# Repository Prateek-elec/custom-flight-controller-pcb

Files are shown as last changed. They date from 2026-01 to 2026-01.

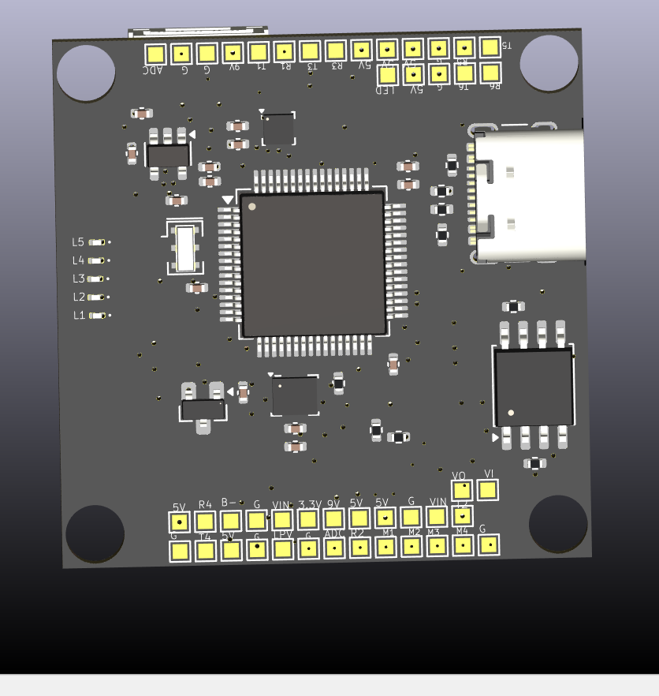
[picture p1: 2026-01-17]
docs/images/Screenshot 2026-01-17 221942.png

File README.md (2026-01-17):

# Custom Drone Flight Controller PCB (KiCad)

A custom-designed drone flight controller PCB built for UAV / robotics applications.
This repository contains schematic + PCB layout designed in **KiCad**, along with documentation and renders.

---

## 🔥 Highlights
- Custom Flight Controller PCB (compact layout)
- Designed for UAV multirotor / robotics use cases
- Includes power regulation, sensor interfaces, and IO headers
- Designed for debugging + expandability

---

## 🧩 Major Blocks (Hardware Architecture)
### ✅ MCU / Processing
- STM32-based microcontroller (flight control core)
- Clocking + reset/boot support

### ✅ Sensors
- IMU interface for attitude estimation (gyro + accel)
- Additional I2C/SPI expansion for future sensors

### ✅ Power System
- Multiple regulated rails for clean operation
- USB/VBUS support
- Protection + filtering for stable power delivery

### ✅ IO / Connectivity
- Motor/ESC outputs (PWM)
- UART ports for telemetry / GPS / RC
- I2C / SPI headers for peripherals
- Status LEDs for debugging/health indication

---

## 🖼️ PCB Preview

### 3D View
3D Render

### Schematic
Schematic

---

## 📂 Repository Structure
- `hardware/kicad/` → KiCad source project files
- `docs/images/` → PCB renders & schematic snapshots
- `fabrication/` → Gerbers, drill files, BOM, pick & place
- `firmware/` → Placeholder for future flight firmware integration

---

## 🛠️ Tools Used
- KiCad (Schematic + PCB + 3D viewer)
- Standard PCB manufacturing flow (Gerber + drill export)

---

## ✅ Project Status
- [x] Schematic completed
- [x] PCB layout completed
- [ ] Full firmware integration (planned)
- [ ] Flight testing & tuning (planned / in-progress)

---

## ⚡ Notes
This is a custom hardware project made for learning, experimentation and UAV development.
You can reuse the structure for educational purposes.

---

## 📌 Author
**Prateek Sarkar**  
UAV Systems | Embedded | PCB Design | Robotics

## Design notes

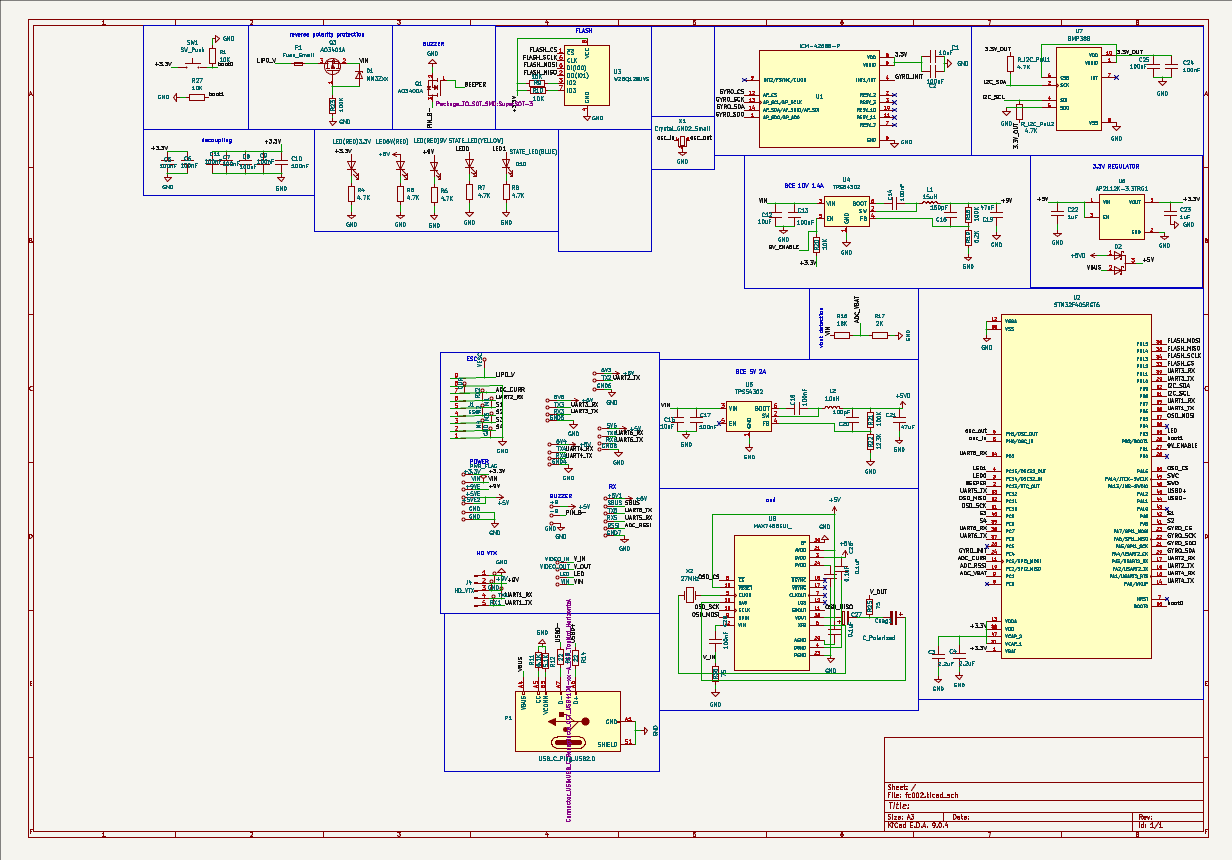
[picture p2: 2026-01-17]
docs/images/Screenshot 2026-01-17 221852.png

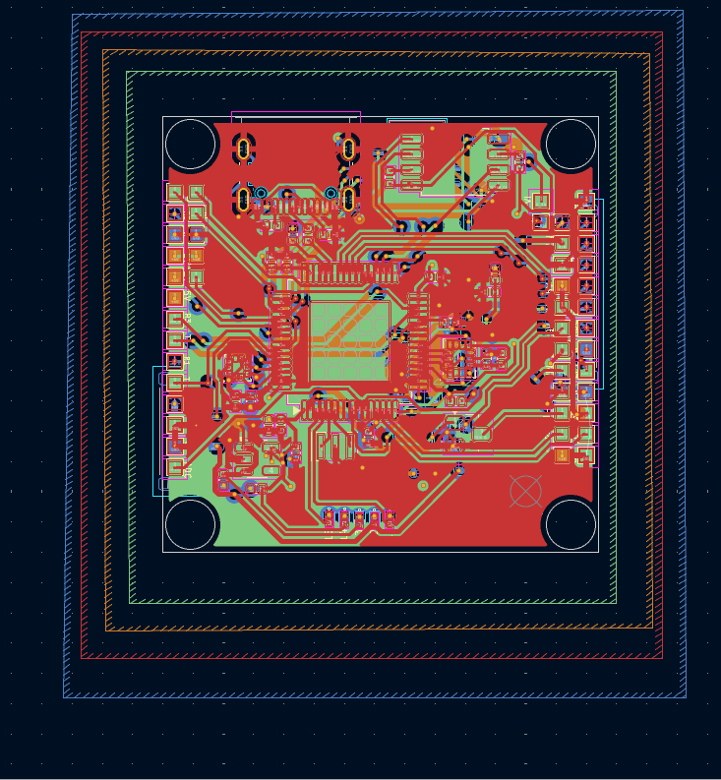
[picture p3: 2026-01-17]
docs/images/Screenshot 2026-01-17 221922.png

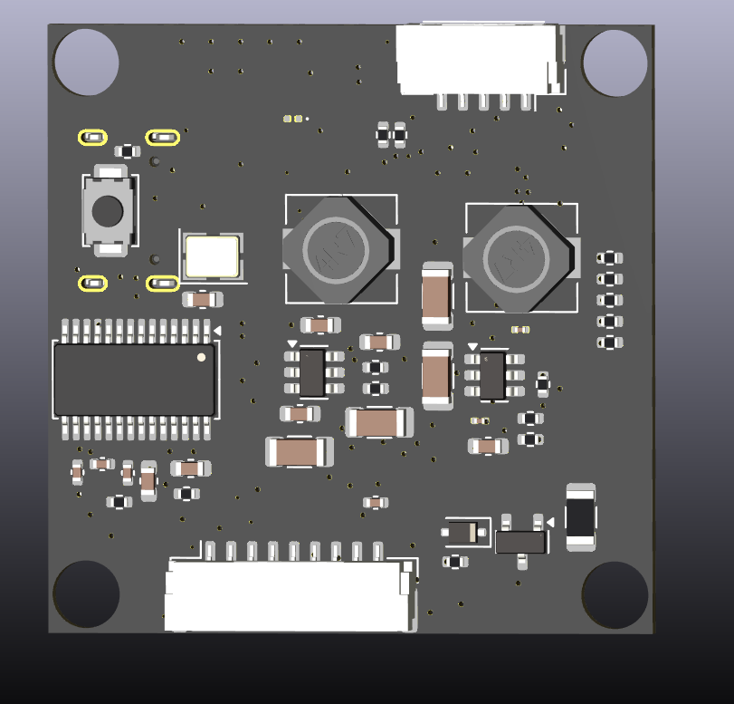
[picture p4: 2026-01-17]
docs/images/Screenshot 2026-01-17 222008.png

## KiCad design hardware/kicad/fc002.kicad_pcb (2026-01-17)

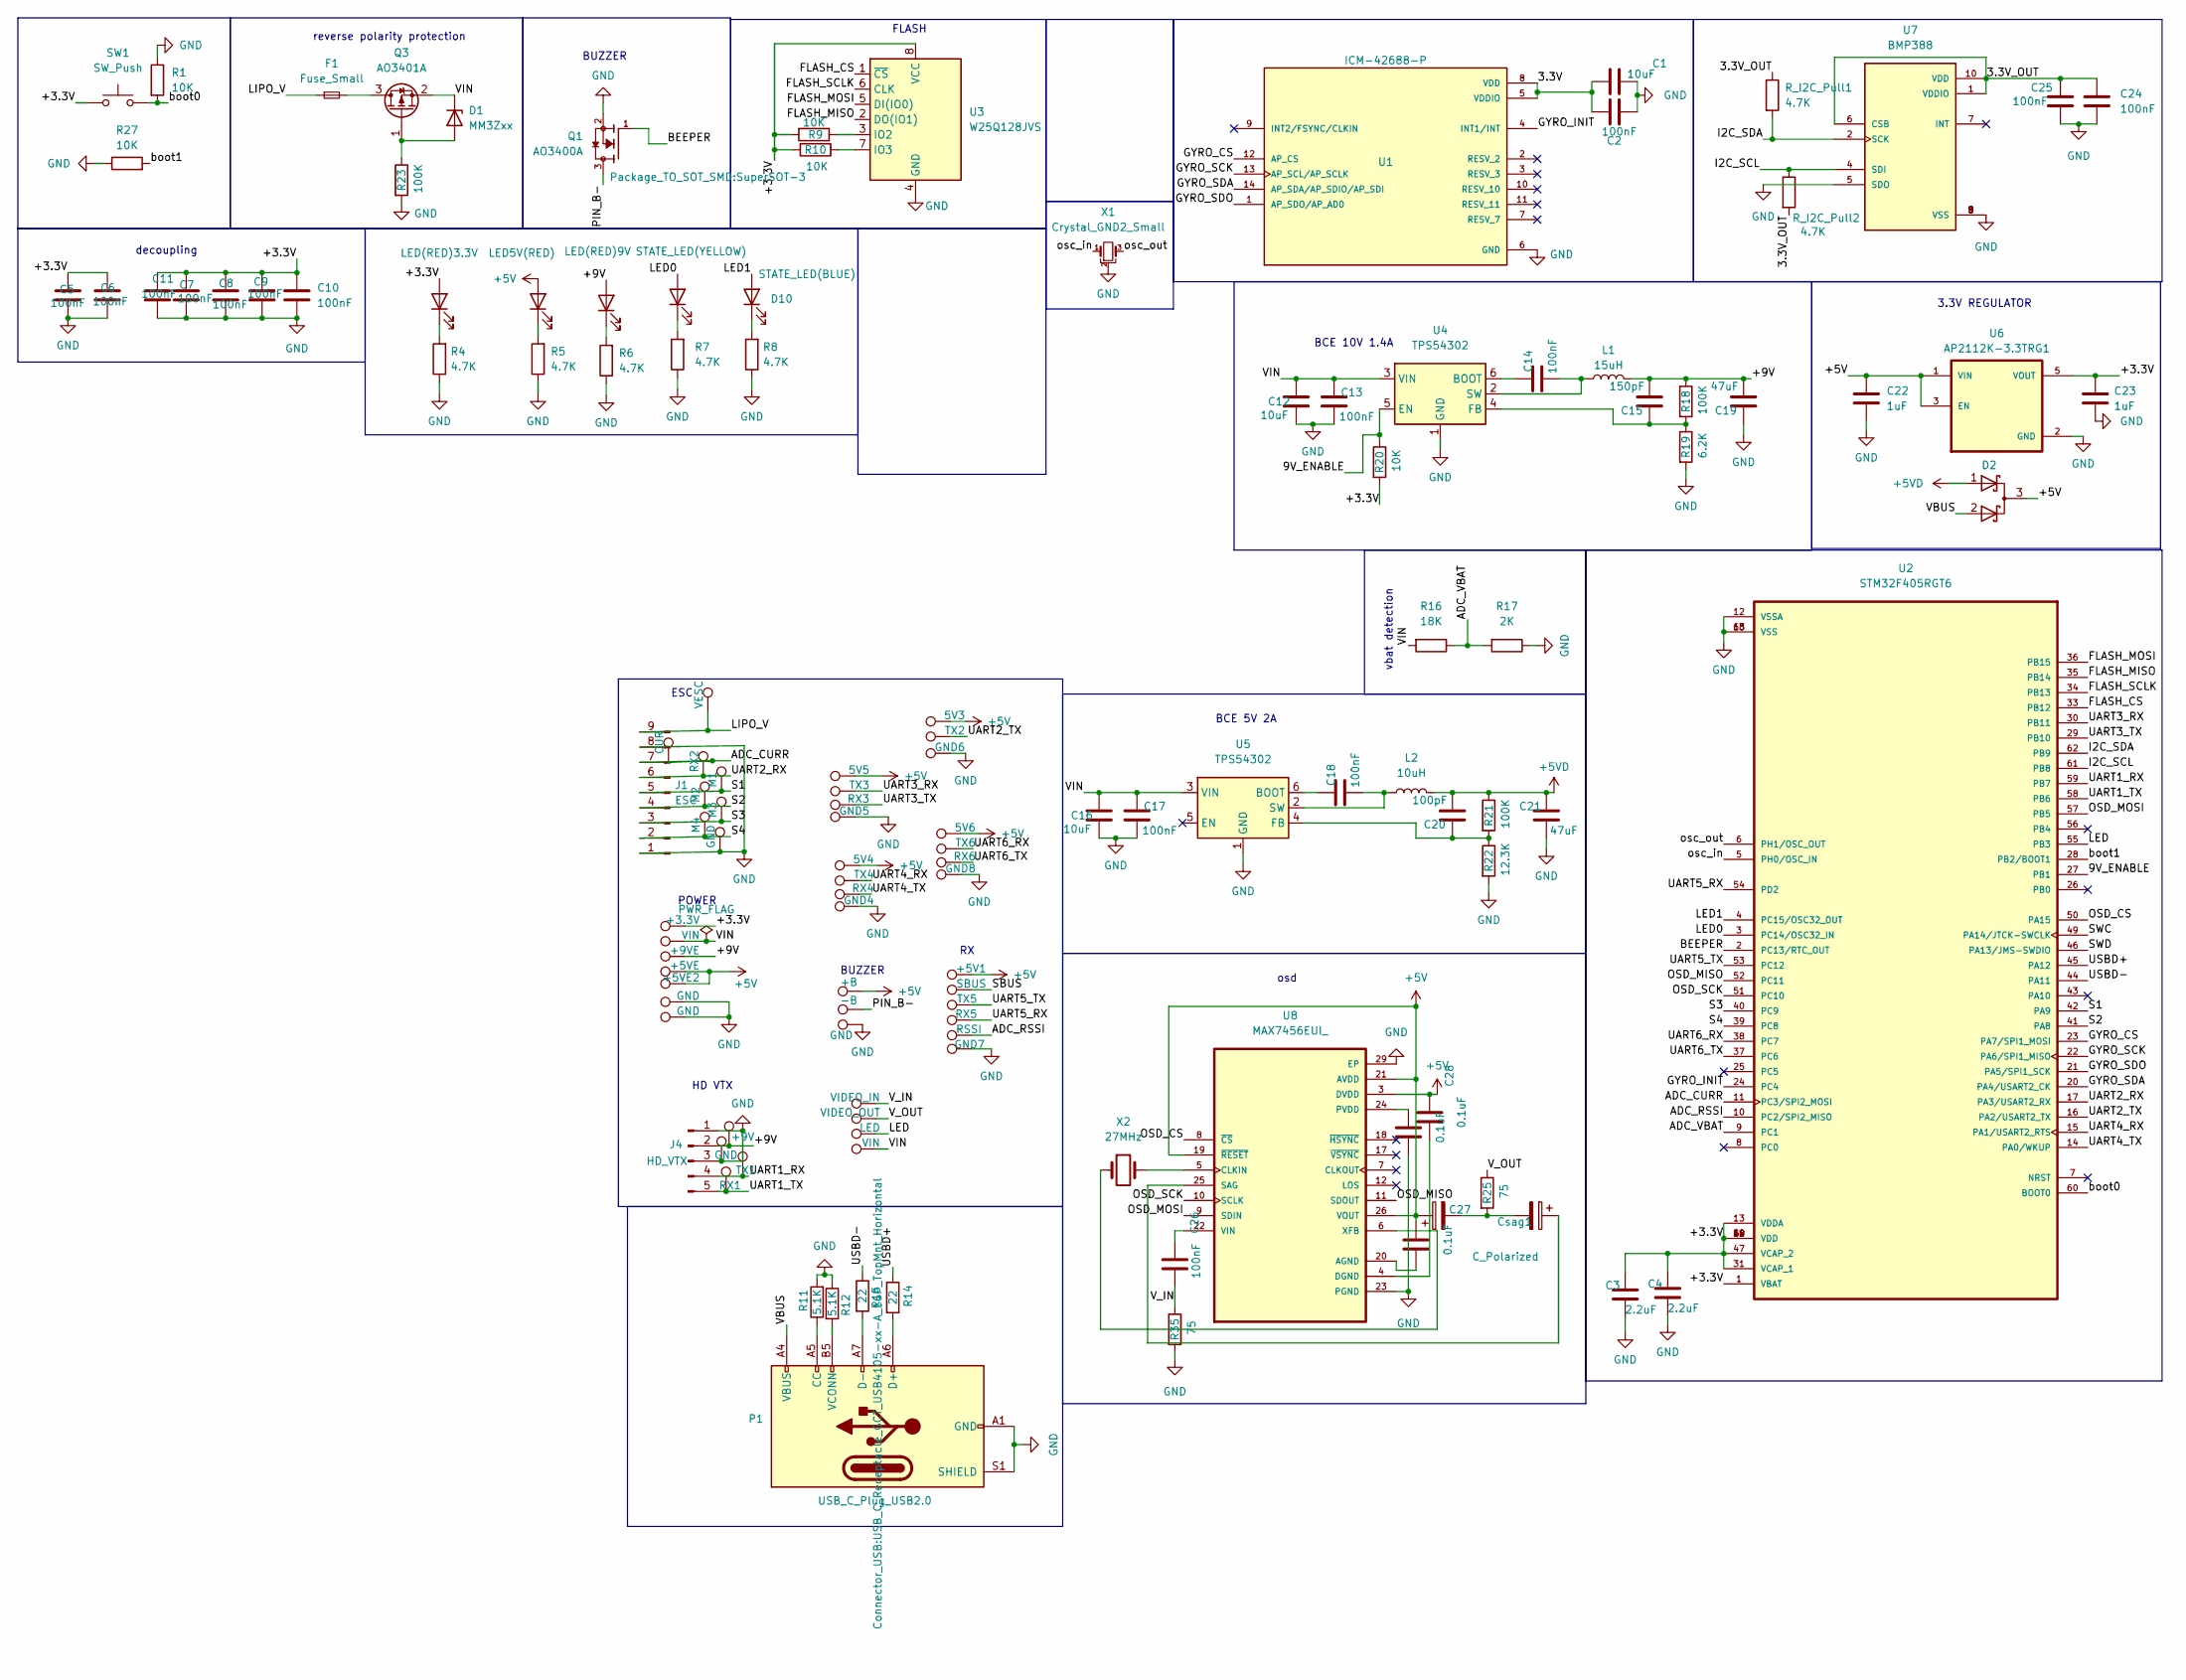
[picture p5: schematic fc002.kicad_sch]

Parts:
C1: 10uF; C_0402_1005Metric
C2, C5, C6, C7, C8, C9, C10, C11, C24, C25, C26: 100nF; C_0402_1005Metric
C3, C4: 2.2uF; C_0402_1005Metric
C12, C16: 10uF; C_1206_3216Metric
C13, C14: 100nF; C_0201_0603Metric
C15: 150pF; C_0603_1608Metric
C17, C18: 100nF; C_0603_1608Metric
C19, C21: 47uF; C_1206_3216Metric
C20: 100pF; C_0603_1608Metric
C22, C23: 1uF; C_0402_1005Metric
C27: C_Polarized; C_0603_1608Metric
C28: 0.1uF; C_0603_1608Metric
C_IMU_100n4, C_IMU_100n5: 0.1uF; C_0402_1005Metric
Csag1: C_Polarized; C_0603_1608Metric
D1: MM3Zxx; D_SOD-323F
D2: D_Schottky_Dual_CommonCathode_AAK_Parallel; D_0201_0603Metric
D10: STATE_LED(BLUE); LED_0201_0603Metric
D11: STATE_LED(YELLOW); LED_0201_0603Metric
D12: LED(RED)9V; LED_0201_0603Metric
D13: LED5V(RED); LED_0201_0603Metric
D14: LED(RED)3.3V; LED_0201_0603Metric
F1: Fuse_Small; Fuse_1206_3216Metric
J1: ESC; JST_GH_SM09B-GHS-TB_1x09-1MP_P1.25mm_Horizontal
J4: HD_VTX; JST_GH_SM05B-GHS-TB_1x05-1MP_P1.25mm_Horizontal
L1: 15uH; L_6.3x6.3_H3
L2: 10uH; L_6.3x6.3_H3
P1: USB_C_Plug_USB2.0; USB_C_Receptacle_GCT_USB4105-xx-A_16P_TopMnt_Horizontal
Q1: AO3400A; SuperSOT-3
Q3: AO3401A; SOT-23
R1, R9, R10, R20, R27: 10K; R_0402_1005Metric
R4, R5, R6, R7, R8: 4.7K; R_0402_1005Metric
R11, R12: 5.1K; R_0402_1005Metric
R14, R15: 22; R_0402_1005Metric
R16: 18K; R_0402_1005Metric
R17: 2K; R_0402_1005Metric
R18, R21, R23: 100K; R_0402_1005Metric
R19: 6.2K; R_0402_1005Metric
R22: 12.3K; R_0402_1005Metric
R25, R35: 75; R_0402_1005Metric
R_I2C_Pull1, R_I2C_Pull2: 4.7K; R_0402_1005Metric
SW1: SW_Push; SW_SPST_TS-1088-xR020
TP1: +9V; TestPoint_Pad_1.0x1.0mm
TP2: TX1; TestPoint_Pad_1.0x1.0mm
TP3: RX1; TestPoint_Pad_1.0x1.0mm
TP4, TP6, TP26, TP32, TP33: GND; TestPoint_Pad_1.0x1.0mm
TP5: -B; TestPoint_Pad_1.0x1.0mm
TP7: +5V1; TestPoint_Pad_1.0x1.0mm
TP8: SBUS; TestPoint_Pad_1.0x1.0mm
TP9: TX5; TestPoint_Pad_1.0x1.0mm
TP10: RX5; TestPoint_Pad_1.0x1.0mm
TP11: RSSI; TestPoint_Pad_1.0x1.0mm
TP12: GND7; TestPoint_Pad_1.0x1.0mm
TP15: VIDEO_IN; TestPoint_Pad_1.0x1.0mm
TP16: VIDEO_OUT; TestPoint_Pad_1.0x1.0mm
TP17: LED; TestPoint_Pad_1.0x1.0mm
TP18, TP28: VIN; TestPoint_Pad_1.0x1.0mm
TP19: VESC; TestPoint_Pad_1.0x1.0mm
TP20: CUR; TestPoint_Pad_1.0x1.0mm
TP21: RX2; TestPoint_Pad_1.0x1.0mm
TP22: M1; TestPoint_Pad_1.0x1.0mm
TP23: M2; TestPoint_Pad_1.0x1.0mm
TP24: M3; TestPoint_Pad_1.0x1.0mm
TP25: M4; TestPoint_Pad_1.0x1.0mm
TP27: +3.3V; TestPoint_Pad_1.0x1.0mm
TP29: +9VE; TestPoint_Pad_1.0x1.0mm
TP30: +5VE; TestPoint_Pad_1.0x1.0mm
TP31: +5VE2; TestPoint_Pad_1.0x1.0mm
TP34: 5V5; TestPoint_Pad_1.0x1.0mm
TP35: TX3; TestPoint_Pad_1.0x1.0mm
TP36: RX3; TestPoint_Pad_1.0x1.0mm
TP37: GND5; TestPoint_Pad_1.0x1.0mm
TP38: 5V4; TestPoint_Pad_1.0x1.0mm
TP39: TX4; TestPoint_Pad_1.0x1.0mm
TP40: RX4; TestPoint_Pad_1.0x1.0mm
TP41: GND4; TestPoint_Pad_1.0x1.0mm
TP42: 5V3; TestPoint_Pad_1.0x1.0mm
TP43: TX2; TestPoint_Pad_1.0x1.0mm
TP44: GND6; TestPoint_Pad_1.0x1.0mm
TP45: 5V6; TestPoint_Pad_1.0x1.0mm
TP46: TX6; TestPoint_Pad_1.0x1.0mm
TP47: RX6; TestPoint_Pad_1.0x1.0mm
TP48: GND8; TestPoint_Pad_1.0x1.0mm
TP49: +B; TestPoint_Pad_1.0x1.0mm
U1: ICM-42688-P; LGA-14_3x2.5mm_P0.5mm_LayoutBorder3x4y; PARTREV 1.2
U2: STM32F405RGT6; LQFP-64-1EP_10x10mm_P0.5mm_EP6.5x6.5mm; PARTREV LTR
U3: W25Q128JVS; SOIC-8_5.3x5.3mm_P1.27mm
U4, U5: TPS54302; SOT-23-6
U6: AP2112K-3.3TRG1; SOT-23-5; PARTREV 2-2
U7: BMP388; ST_HLGA-10_2x2mm_P0.5mm_LayoutBorder3x2y; PARTREV 1.1
U8: MAX7456EUI_; TSSOP-28_4.4x9.7mm_P0.65mm
X1: Crystal_GND2_Small; Resonator_SMD_Murata_CSTxExxV-3Pin_3.0x1.1mm
X2: 27MHz; Crystal_SMD_SeikoEpson_FA238-4Pin_3.2x2.5mm

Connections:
+5V: C22.1, C27.1, C28.2, C_IMU_100n5.2, D2.3 (A), D13.2 (A), TP7.1, TP30.1, TP31.1, TP34.1, TP38.1, TP42.1, TP45.1, TP49.1, U6.1 (VIN), U6.3 (EN), U8.3 (DVDD), U8.19 (~RESET), U8.21 (AVDD), U8.26 (VOUT)
+5VD: C20.2, C21.2, D2.1 (K), L2.2, R21.1
/3.3V: C1.1, C2.1, U1.5 (VDDIO), U1.8 (VDD)
/3.3V_OUT: C24.1, C25.1, R_I2C_Pull1.1, R_I2C_Pull2.2, U7.1 (VDDIO), U7.6 (CSB), U7.10 (VDD)
/9V_ENABLE: R20.1, U2.27 (PB1), U4.5 (EN)
/+3.3V: C3.2, C4.2, C5.1, C6.1, C7.1, C8.1, C9.1, C10.1, C11.1, C23.1, D14.2 (A), R9.2, R10.2, R20.2, SW1.1, TP27.1, U2.1 (VBAT), U2.13 (VDDA), U2.19 (VDD), U2.31 (VCAP_1), U2.32 (VDD), U2.47 (VCAP_2), U2.48 (VDD), U2.64 (VDD), U3.8 (VCC), U6.5 (VOUT)
/+9V: C15.2, C19.2, D12.2 (A), J4.2, L1.2, R18.1, TP1.1, TP29.1
/ADC_CURR: J1.7, TP20.1, U2.11 (PC3/SPI2_MOSI)
/ADC_RSSI: TP11.1, U2.10 (PC2/SPI2_MISO)
/ADC_VBAT: R16.1, R17.2, U2.9 (PC1)
/BEEPER: Q1.1, U2.2 (PC13/RTC_OUT)
/FLASH_CS: U2.33 (PB12), U3.1 (~CS)
/FLASH_MISO: U2.35 (PB14), U3.2 (DO(IO1))
/FLASH_MOSI: U2.36 (PB15), U3.5 (DI(IO0))
/FLASH_SCLK: U2.34 (PB13), U3.6 (CLK)
/GYRO_CS: U1.12 (AP_CS), U2.23 (PA7/SPI1_MOSI)
/GYRO_INIT: U1.4 (INT1/INT), U2.24 (PC4)
/GYRO_SCK: U1.13 (AP_SCL/AP_SCLK), U2.22 (PA6/SPI1_MISO)
/GYRO_SDA: U1.14 (AP_SDA/AP_SDIO/AP_SDI), U2.20 (PA4/USART2_CK)
/GYRO_SDO: U1.1 (AP_SDO/AP_AD0), U2.21 (PA5/SPI1_SCK)
/I2C_SCL: R_I2C_Pull2.1, U2.61 (PB8), U7.4 (SDI)
/I2C_SDA: R_I2C_Pull1.2, U2.62 (PB9), U7.2 (SCK)
/LED: TP17.1, U2.55 (PB3)
/LED0: D11.2 (A), U2.3 (PC14/OSC32_IN)
/LED1: D10.2 (A), U2.4 (PC15/OSC32_OUT)
/LIPO_V: F1.1, J1.9, TP19.1
/OSD_CS: U2.50 (PA15), U8.8 (~CS)
/OSD_MISO: U2.52 (PC11), U8.11 (SDOUT)
/OSD_MOSI: U2.57 (PB5), U8.9 (SDIN)
/OSD_SCK: U2.51 (PC10), U8.10 (SCLK)
/PIN_B-: Q1.3, TP5.1
/S1: J1.5, TP22.1, U2.42 (PA9)
/S2: J1.4, TP23.1, U2.41 (PA8)
/S3: J1.3, TP24.1, U2.40 (PC9)
/S4: J1.2, TP25.1, U2.39 (PC8)
/SWC: U2.49 (PA14/JTCK-SWCLK)
/SWD: U2.46 (PA13/JMS-SWDIO)
/UART1_RX: J4.4, TP2.1, U2.59 (PB7)
/UART1_TX: J4.5, TP3.1, U2.58 (PB6)
/UART2_RX: J1.6, TP21.1, U2.17 (PA3/USART2_RX)
/UART2_TX: TP43.1, U2.16 (PA2/USART2_TX)
/UART3_RX: TP35.1, U2.30 (PB11)
/UART3_TX: TP36.1, U2.29 (PB10)
/UART4_RX: TP39.1, U2.15 (PA1/USART2_RTS)
/UART4_TX: TP40.1, U2.14 (PA0/WKUP)
/UART5_RX: TP10.1, U2.54 (PD2)
/UART5_TX: TP9.1, U2.53 (PC12)
/UART6_RX: TP46.1, U2.38 (PC7)
/UART6_TX: TP47.1, U2.37 (PC6)
/USBD+: R14.1, U2.45 (PA12)
/USBD-: R15.1, U2.44 (PA11)
/VBUS: D2.2 (K), P1.A4 (VBUS), P1.A9 (VBUS), P1.B4 (VBUS), P1.B9 (VBUS)
/VIN: C12.1, C13.1, C16.1, C17.1, D1.1 (K), Q3.2 (S), R16.2, TP18.1, TP28.1, U4.3 (VIN), U5.3 (VIN)
/V_IN: C26.1, R35.1, TP15.1
/V_OUT: R25.1, TP16.1
/boot0: R1.2, SW1.2, U2.60 (BOOT0)
/boot1: R27.2, U2.28 (PB2/BOOT1)
/osc_in: U2.5 (PH0/OSC_IN), X1.1
/osc_out: U2.6 (PH1/OSC_OUT), X1.3
GND: C1.2, C2.2, C3.1, C4.1, C5.2, C6.2, C7.2, C8.2, C9.2, C10.2, C11.2, C12.2, C13.2, C16.2, C17.2, C19.1, C21.1, C22.2, C23.2, C24.2, C25.2, C_IMU_100n4.1, J1.1, J1.8, J4.1, J4.3, P1.A1 (GND), P1.A12 (GND), P1.B1 (GND), P1.B12 (GND), P1.S1 (SHIELD), Q1.2, R1.1, R4.1, R5.1, R6.1, R7.1, R8.1, R11.2, R12.1, R17.1, R19.2, R22.2, R23.2, R27.1, R35.2, TP4.1, TP6.1, TP12.1, TP26.1, TP32.1, TP33.1, TP37.1, TP41.1, TP44.1, TP48.1, U1.6 (GND), U2.12 (VSSA), U2.18 (VSS), U2.63 (VSS), U3.4 (GND), U4.1 (GND), U5.1 (GND), U6.2 (GND), U7.3 (VSS), U7.5 (SDO), U7.8 (VSS), U7.9 (VSS), U8.23 (PGND), U8.29 (EP), X1.2
unnamed: C27.2, Csag1.2, R25.2
unnamed: D1.2 (A), Q3.1 (G), R23.1
unnamed: D10.1 (K), R8.2
unnamed: D11.1 (K), R7.2
unnamed: D12.1 (K), R6.2
unnamed: D13.1 (K), R5.2
unnamed: D14.1 (K), R4.2
unnamed: P1.A5 (CC), R11.1
unnamed: P1.A6 (D+), R14.2
unnamed: P1.A7 (D-), R15.2
unnamed: P1.B5 (VCONN), R12.2
unnamed: F1.2, Q3.3 (D)
unnamed: R9.1, U3.3 (IO2)
unnamed: R10.1, U3.7 (IO3)
unnamed: C14.1, U4.6 (BOOT)
unnamed: C15.1, R18.2, R19.1, U4.4 (FB)
unnamed: C14.2, L1.1, U4.2 (SW)
unnamed: C18.1, U5.6 (BOOT)
unnamed: C20.1, R21.2, R22.1, U5.4 (FB)
unnamed: C18.2, L2.1, U5.2 (SW)
unnamed: C_IMU_100n5.1, U8.20 (AGND)
unnamed: U8.5 (CLKIN), X2.2
unnamed: C28.1, U8.4 (DGND)
unnamed: C_IMU_100n4.2, U8.24 (PVDD)
unnamed: Csag1.1, U8.25 (SAG)
unnamed: C26.2, U8.22 (VIN)
unnamed: U8.6 (XFB), X2.1

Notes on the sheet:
HD VTX
3.3V REGULATOR
BUZZER
BCE 5V 2A
reverse polarity protection
vbat detection
osd
decoupling
POWER
ESC
BCE 10V 1.4A
FLASH

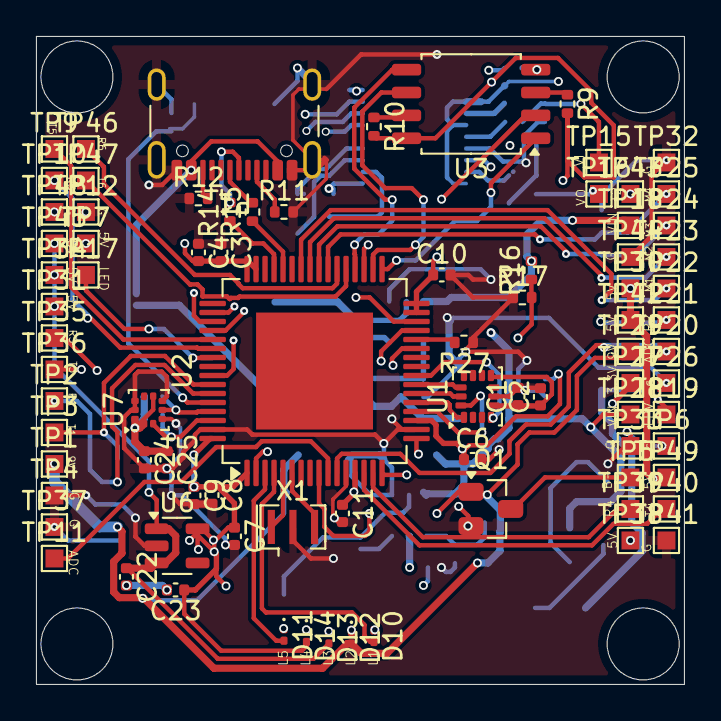
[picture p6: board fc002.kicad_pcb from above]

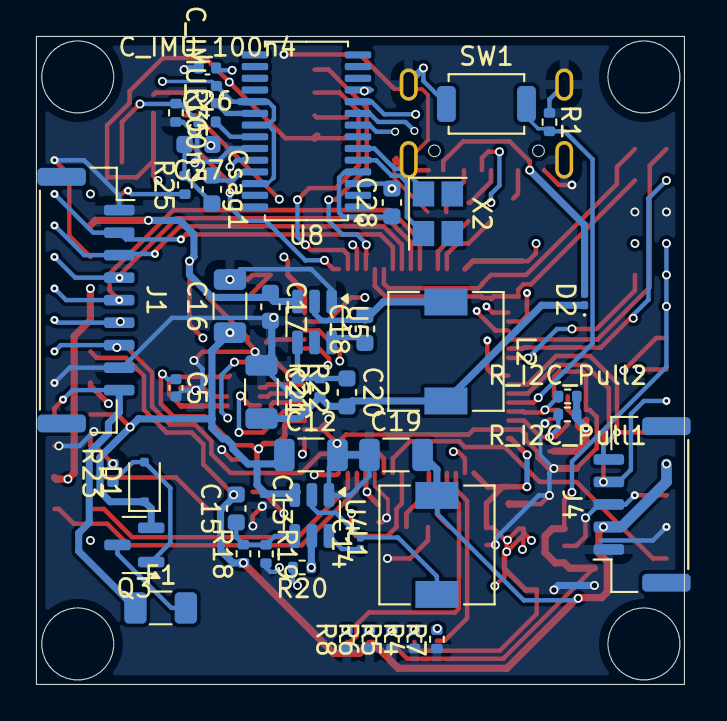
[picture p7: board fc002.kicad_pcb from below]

Board: 4 copper layers, 36.0 x 36.0 mm, 128 parts (46 on the bottom side), 85 nets.
